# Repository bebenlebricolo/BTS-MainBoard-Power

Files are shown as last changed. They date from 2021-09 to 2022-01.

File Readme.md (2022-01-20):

# BTS-Mainboard-Power's Index

- [BTS-Mainboard-Power's Index](#bts-mainboard-powers-index)
- [Description (Revision 0.2.0)](#description-revision-020)

# Description (Revision 0.2.0)
Beer thermoregulation system mainboard  - power section
This single sided board made a 4 layers PCB stackup carries an H-bridge which drives 8 peltier modules (10x10mm, 12VDC, 6.7A each) in parallel in either direction.

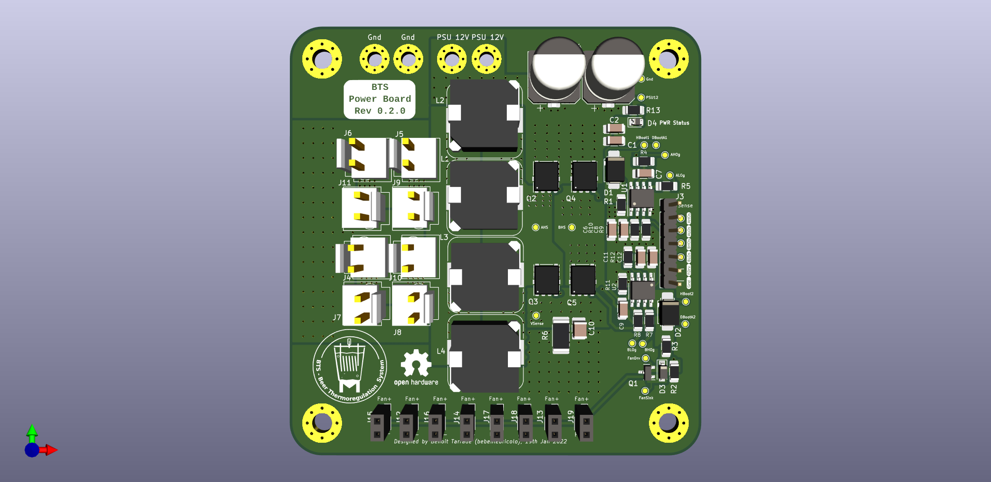
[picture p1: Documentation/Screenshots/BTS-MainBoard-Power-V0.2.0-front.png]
Board screenshot front

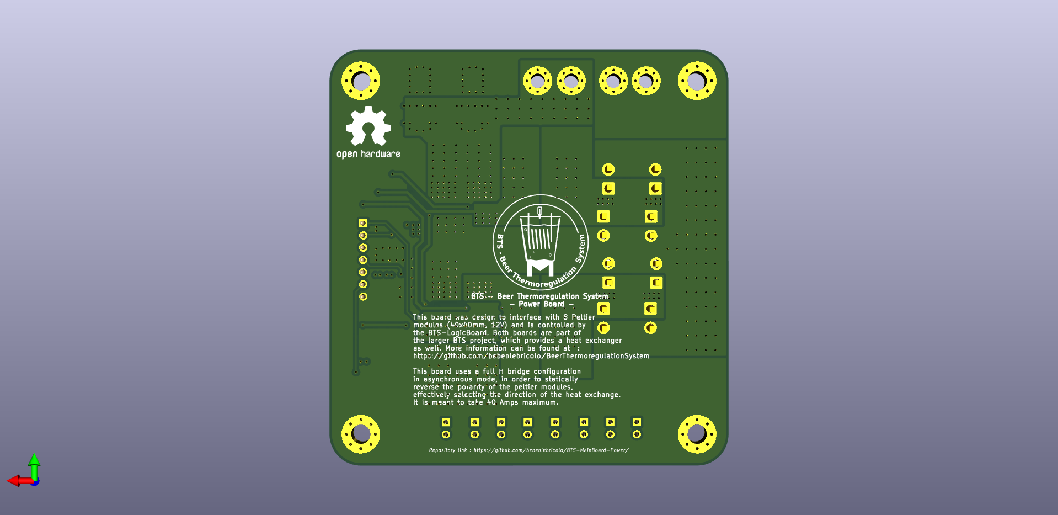
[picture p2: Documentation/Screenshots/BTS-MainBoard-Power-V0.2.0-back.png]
Board screenshot back


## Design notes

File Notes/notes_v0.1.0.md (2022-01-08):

# BTS-Mainboard-Power's Index

- [BTS-Mainboard-Power's Index](#bts-mainboard-powers-index)
- [Description](#description)
- [Modularity](#modularity)
- [Issues and limitations](#issues-and-limitations)

# Description
Beer thermoregulation system mainboard  - power section
This single sided board made with aluminum substrate carries an H-bridge which drives 8 peltier modules (10x10mm, 12VDC, 6.7A each) in parallel in either direction.
It was designed with modularity in mind and good thermal dissipation properties, and this alone drove the design into the aluminum substrate land.

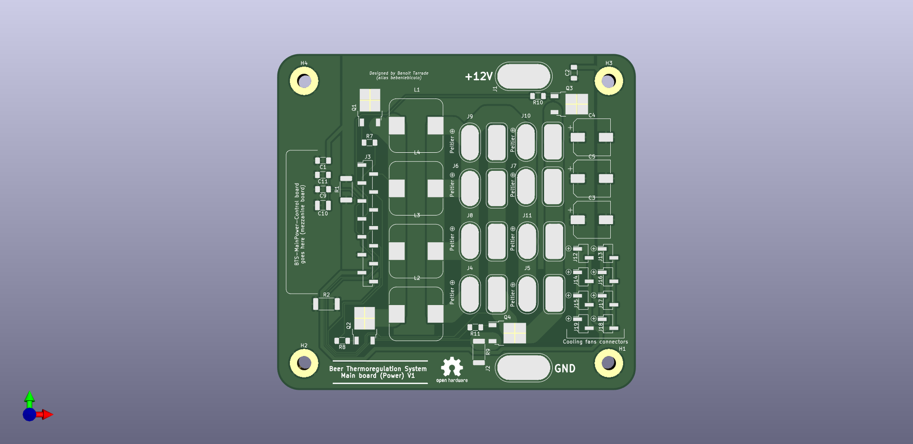
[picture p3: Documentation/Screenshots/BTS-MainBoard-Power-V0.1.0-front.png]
Board screenshot


# Modularity
Modularity is achieved via a standard 2.54 mm pitch header connector which is used to carry the Control board in a mezzanine configuration (boards V0.1.0 and V0.2.0).
It allows to iterate on the control board without having to change anything on the power board itself.

# Issues and limitations
This board has several critical issues that renders it more or less useless.
1. Gate drivers do not implement shoot through protection !
   * As a consequence, I destroyed many mosfets many times because of transient signals being interpreted either as high or low (due to noise on driver's input signal). This resulted in many shoot through occurrences, and if the board effectively spread and dissipated the heat, it was not enough to take the 40A/12V power burst (and potentially even much more).
2. Soldering on this board is a real nightmare
   * I can say the aluminum substrate is very nice when it comes to dissipate heat. So nice that it made the assembly process a real nightmare, without speaking about the single-sidedness of the board which prevents any through-hole component use.
3. The return current track for the ALO mosfet is far to skinny ! It still has the default 0.25 mm width, no doubt as to why it could not handle high powers.
4. Having the mezzanine control board increases chances to pick up EMI and noise, which is not nice.
5. Mosfets are not as "modern" as they could be, I think I can switch to smaller ones that will handle more current just as well
6. Mosfets are spread out on the board the same way they are layed out in schematic : as a consequence they are quite far away from the gate driver, with a ground plane under them still (the aluminum substrate is grounded). Shortening the gate path will help improve their performance and reduce shoot-through potentialities.

All those issues shall be taken care of in the next revision.
Amongts other things, mosfets will be relocated, the board will be switched to a 4 layer configuration and mosfet drivers will finally be carried by this board as well.
I won't use the mezzanine topology anymore, so the whole Beer Thermoregulation System will only need 2 boards instead of 3 (which is more cost effictive).
As we'll be losing the good thermal conductivity of the aluminum substrate, special care shall be taken in order to dissipate the heat properly.
Finally, tracks will also need to be beefed up a little bit, eventually providing a way to add thick copper wire on the surface of the board in order to safely carry the 40A+.

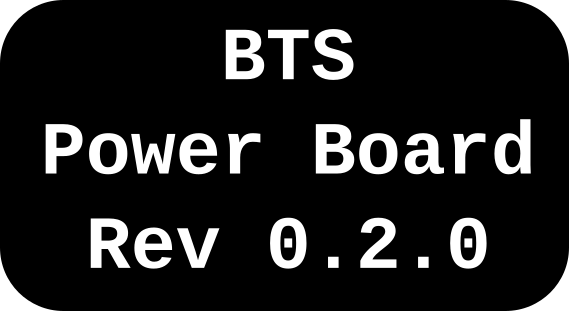
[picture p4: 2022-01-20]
Hardware/Drawings/BoardMainLabel.png

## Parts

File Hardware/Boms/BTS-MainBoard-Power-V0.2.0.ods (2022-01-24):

Reference | Quantity | Value | Footprint | Datasheet
C1 C2 C8 C11 | 4 | 1uF | Capacitor_SMD:C_1206_3216Metric_Pad1.33x1.80mm_HandSolder
C10 | 1 | 22nF | Capacitor_SMD:C_1210_3225Metric_Pad1.33x2.70mm_HandSolder
C3 C4 | 2 | 470uF | Capacitor_SMD:CP_Elec_10x10
C6 C7 C9 C12 | 4 | 100nF | Capacitor_SMD:C_1206_3216Metric_Pad1.33x1.80mm_HandSolder
D1 D2 | 2 | SS56B | BTS-MainBoard-Power:SS56B | https://docs.rs-online.com/99ea/0900766b814bbf94.pdf
D3 | 1 | 1N4148W | Diode_SMD:D_SOD-123 | https://www.vishay.com/docs/85748/1n4148w.pdf
D4 | 1 | LED | Diode_SMD:D_0805_2012Metric
H1 H2 H3 H4 | 4 | MountingHole_Pad | MountingHole:MountingHole_4mm_Pad_Via
H5 H6 H7 H8 | 4 | MountingHole_Pad | MountingHole:MountingHole_3mm_Pad_Via
J12 J13 J14 J15 J16 J17 J18 J19 | 8 | FanConn | Connector_PinSocket_2.54mm:PinSocket_1x02_P2.54mm_Vertical
J3 | 1 | LogicBoardConnector | Connector_PinHeader_2.54mm:PinHeader_1x07_P2.54mm_Vertical
J4 J5 J6 J7 J8 J9 J10 J11 | 8 | PeCon | BTS-MainBoard-Power:TE_1-1123723-2_1x02_P3.96mm_8Amps_Vertical
L1 L2 L3 L4 | 4 | SRP1270-100M | BTS-MainBoard-Power:L_Bourns_SRP1270
Q1 | 1 | DMG3418L | Package_TO_SOT_SMD:SOT-23
Q2 Q3 Q4 Q5 | 4 | NTMFS5H419NL | BTS-MainBoard-Power:NTMFS5G419NL | https://docs.rs-online.com/31fe/0900766b816e75a2.pdf
R1 R3 R4 R5 R7 R8 | 6 | 3.3 | Resistor_SMD:R_1206_3216Metric_Pad1.30x1.75mm_HandSolder
R2 R13 | 2 | 1k | Resistor_SMD:R_1206_3216Metric_Pad1.30x1.75mm_HandSolder
R6 | 1 | 0.01 | Resistor_SMD:R_2512_6332Metric_Pad1.40x3.35mm_HandSolder
R9 R10 R11 R12 | 4 | 220 | Resistor_SMD:R_1206_3216Metric_Pad1.30x1.75mm_HandSolder
TP1 TP2 TP3 TP4 TP5 TP6 TP7 TP8 TP9 TP10 TP11 TP12 TP13 TP14 TP15 TP16 TP17 TP18 TP19 | 19 | TestPoint | TestPoint:TestPoint_Pad_D1.0mm
U1 U2 | 2 | LM5109BMA | Package_SO:SOIC-8_3.9x4.9mm_P1.27mm | http://www.ti.com/lit/ds/symlink/lm5109b.pdf

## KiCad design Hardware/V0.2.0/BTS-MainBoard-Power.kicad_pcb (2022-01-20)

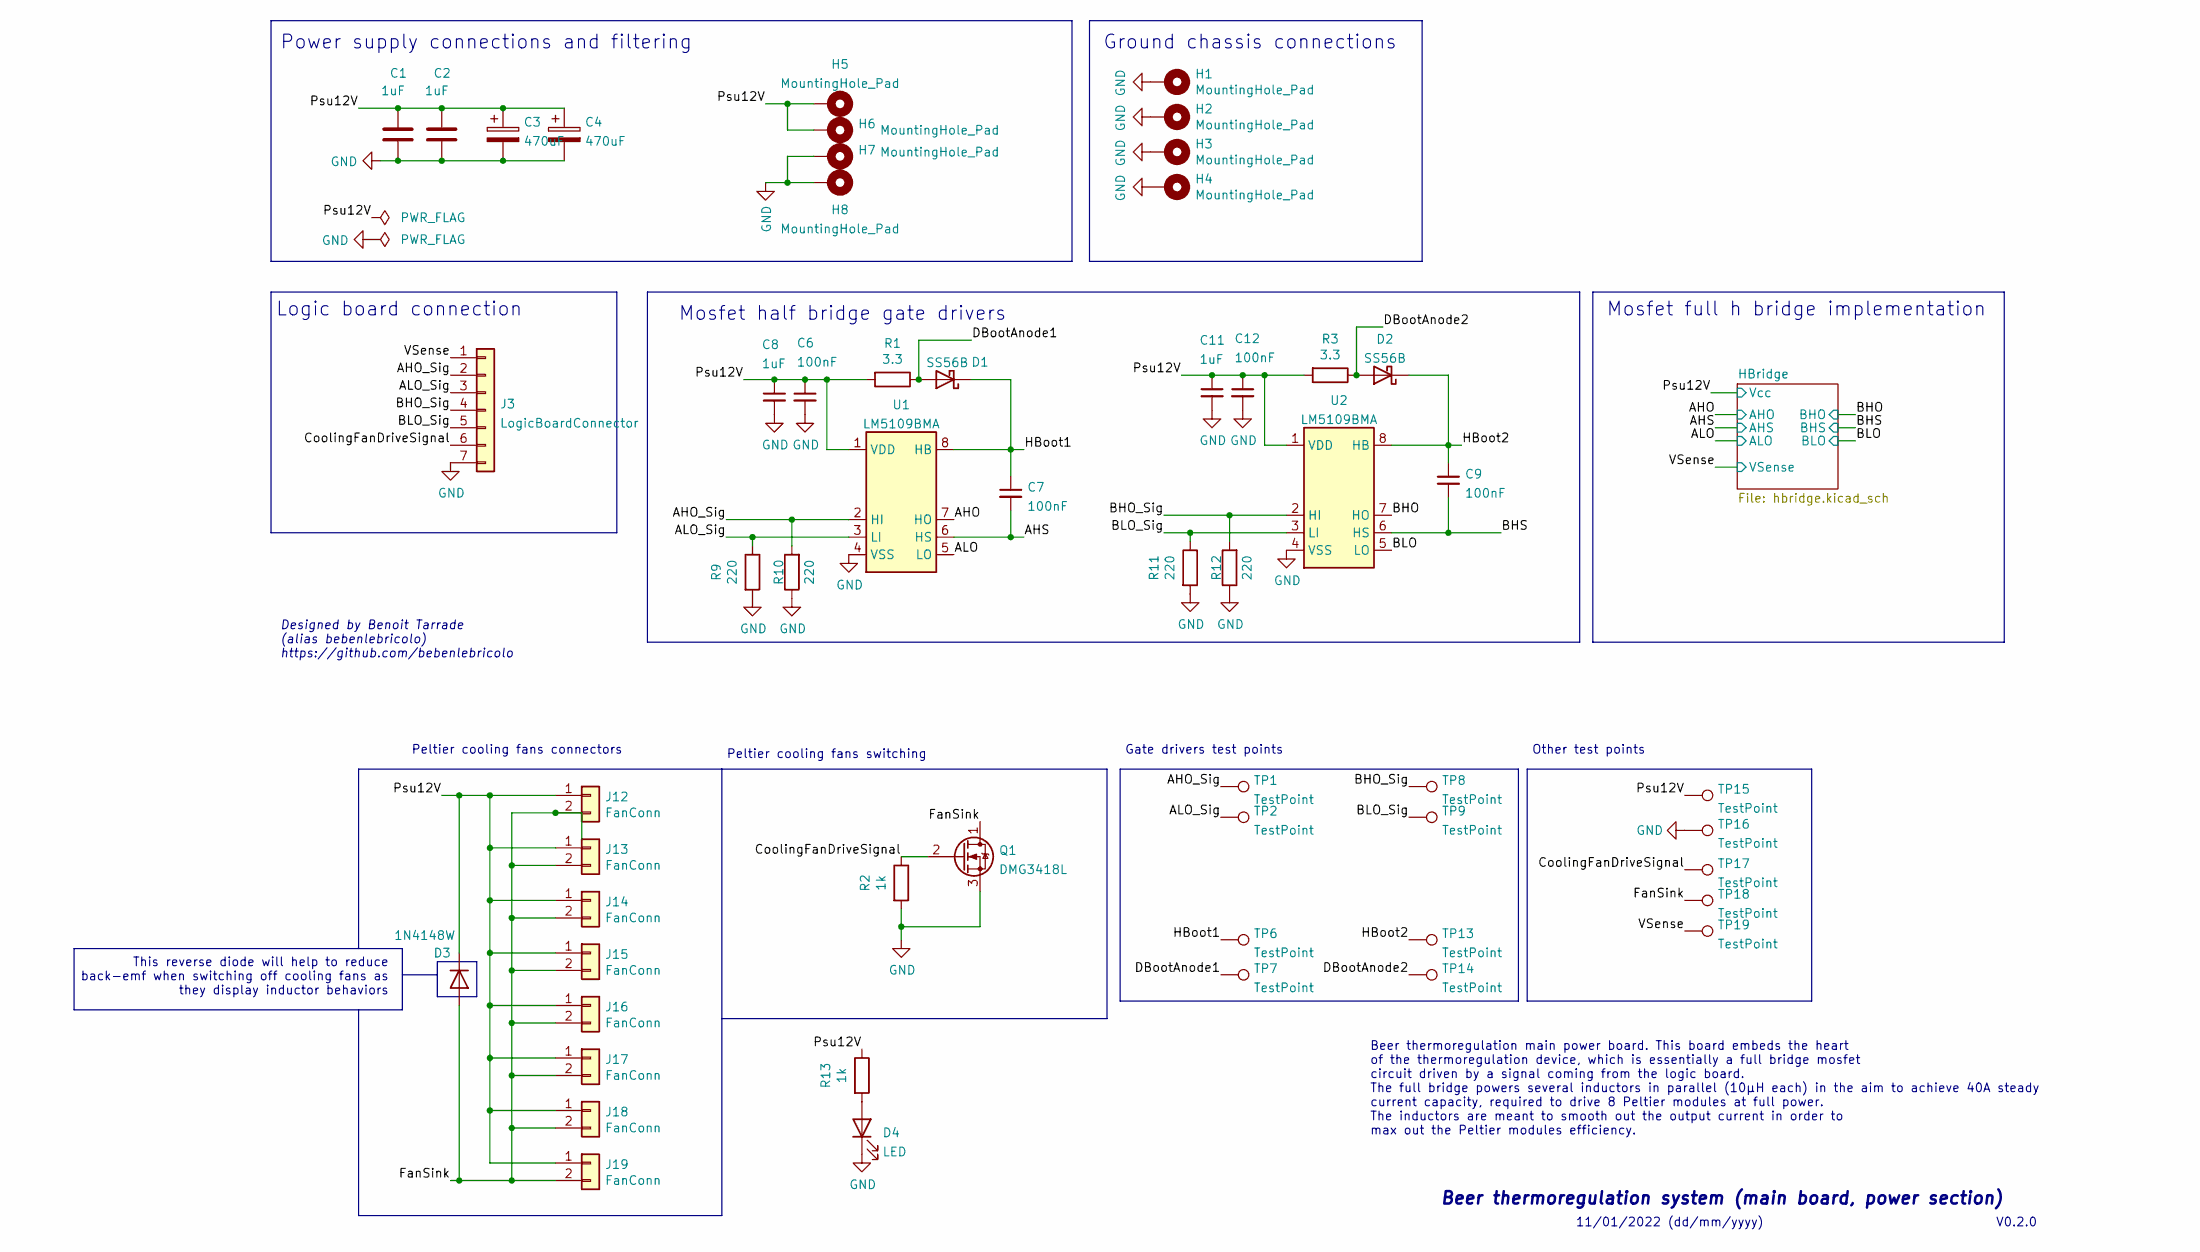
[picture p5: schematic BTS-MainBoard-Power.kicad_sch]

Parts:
C1, C2, C8, C11: 1uF; C_1206_3216Metric_Pad1.33x1.80mm_HandSolder
C3, C4: 470uF; CP_Elec_10x10
C6, C7, C9, C12: 100nF; C_1206_3216Metric_Pad1.33x1.80mm_HandSolder
D1, D2: SS56B
D3: 1N4148W; D_SOD-123
D4: LED; D_0805_2012Metric
H1, H2, H3, H4: MountingHole_Pad; MountingHole_4mm_Pad_Via
H5, H6, H7, H8: MountingHole_Pad; MountingHole_3mm_Pad_Via
J3: LogicBoardConnector; PinHeader_1x07_P2.54mm_Vertical
J12, J13, J14, J15, J16, J17, J18, J19: FanConn; PinSocket_1x02_P2.54mm_Vertical
Q1: DMG3418L; SOT-23
R1, R3: 3.3; R_1206_3216Metric_Pad1.30x1.75mm_HandSolder
R2, R13: 1k; R_1206_3216Metric_Pad1.30x1.75mm_HandSolder
R9, R10, R11, R12: 220; R_1206_3216Metric_Pad1.30x1.75mm_HandSolder
TP1, TP2, TP6, TP7, TP8, TP9, TP13, TP14, TP15, TP16, TP17, TP18, TP19: TestPoint; TestPoint_Pad_D1.0mm
U1, U2: LM5109BMA; SOIC-8_3.9x4.9mm_P1.27mm

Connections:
/AHO: U1.7 (HO); also elsewhere on the board
/AHO_Sig: J3.2, R10.2, TP1.1, U1.2 (HI)
/AHS: C7.2, U1.6 (HS); also elsewhere on the board
/ALO: U1.5 (LO); also elsewhere on the board
/ALO_Sig: J3.3, R9.1, TP2.1, U1.3 (LI)
/BHO: U2.7 (HO); also elsewhere on the board
/BHO_Sig: J3.4, R12.2, TP8.1, U2.2 (HI)
/BHS: C9.2, U2.6 (HS); also elsewhere on the board
/BLO: U2.5 (LO); also elsewhere on the board
/BLO_Sig: J3.5, R11.1, TP9.1, U2.3 (LI)
/CoolingFanDriveSignal: J3.6, Q1.2 (G), R2.1, TP17.1
/DBootAnode1: D1.2 (A), R1.1, TP7.1
/DBootAnode2: D2.2 (A), R3.1, TP14.1
/FanSink: D3.2 (A), J12.2, J13.2, J14.2, J15.2, J16.2, J17.2, J18.2, J19.2, Q1.1 (D), TP18.1
/HBoot1: C7.1, D1.1 (K), TP6.1, U1.8 (HB)
/HBoot2: C9.1, D2.1 (K), TP13.1, U2.8 (HB)
/Psu12V: C1.1, C2.1, C3.1, C4.1, C6.1, C8.1, C11.1, C12.1, D3.1 (K), H5.1, H6.1, J12.1, J13.1, J14.1, J15.1, J16.1, J17.1, J18.1, J19.1, R1.2, R3.2, R13.1, TP15.1, U1.1 (VDD), U2.1 (VDD); also elsewhere on the board
/VSense: J3.1, TP19.1; also elsewhere on the board
GND: C1.2, C2.2, C3.2, C4.2, C6.2, C8.2, C11.2, C12.2, D4.1 (K), H1.1, H2.1, H3.1, H4.1, H7.1, H8.1, J3.7, Q1.3 (S), R2.2, R9.2, R10.1, R11.2, R12.1, TP16.1, U1.4 (VSS), U2.4 (VSS); also elsewhere on the board
unnamed: D4.2 (A), R13.2

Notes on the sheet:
Peltier cooling fans connectors
Gate drivers test points
Logic board connection
Other test points
This reverse diode will help to reduce back-emf when switching off cooling fans as they display inductor behaviors
Mosfet half bridge gate drivers
Designed by Benoit Tarrade (alias bebenlebricolo) https://github.com/bebenlebricolo
11/01/2022 (dd/mm/yyyy)
Ground chassis connections
Peltier cooling fans switching
Mosfet full h bridge implementation
Power supply connections and filtering
V0.2.0
Beer thermoregulation main power board. This board embeds the heart of the thermoregulation device, which is essentially a full bridge mosfet circuit driven by a signal coming from the logic board. The full bridge powers several inductors in parallel (10µH each) in the aim to achieve 40A steady cur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
Beer thermoregulation system (main board, power section)

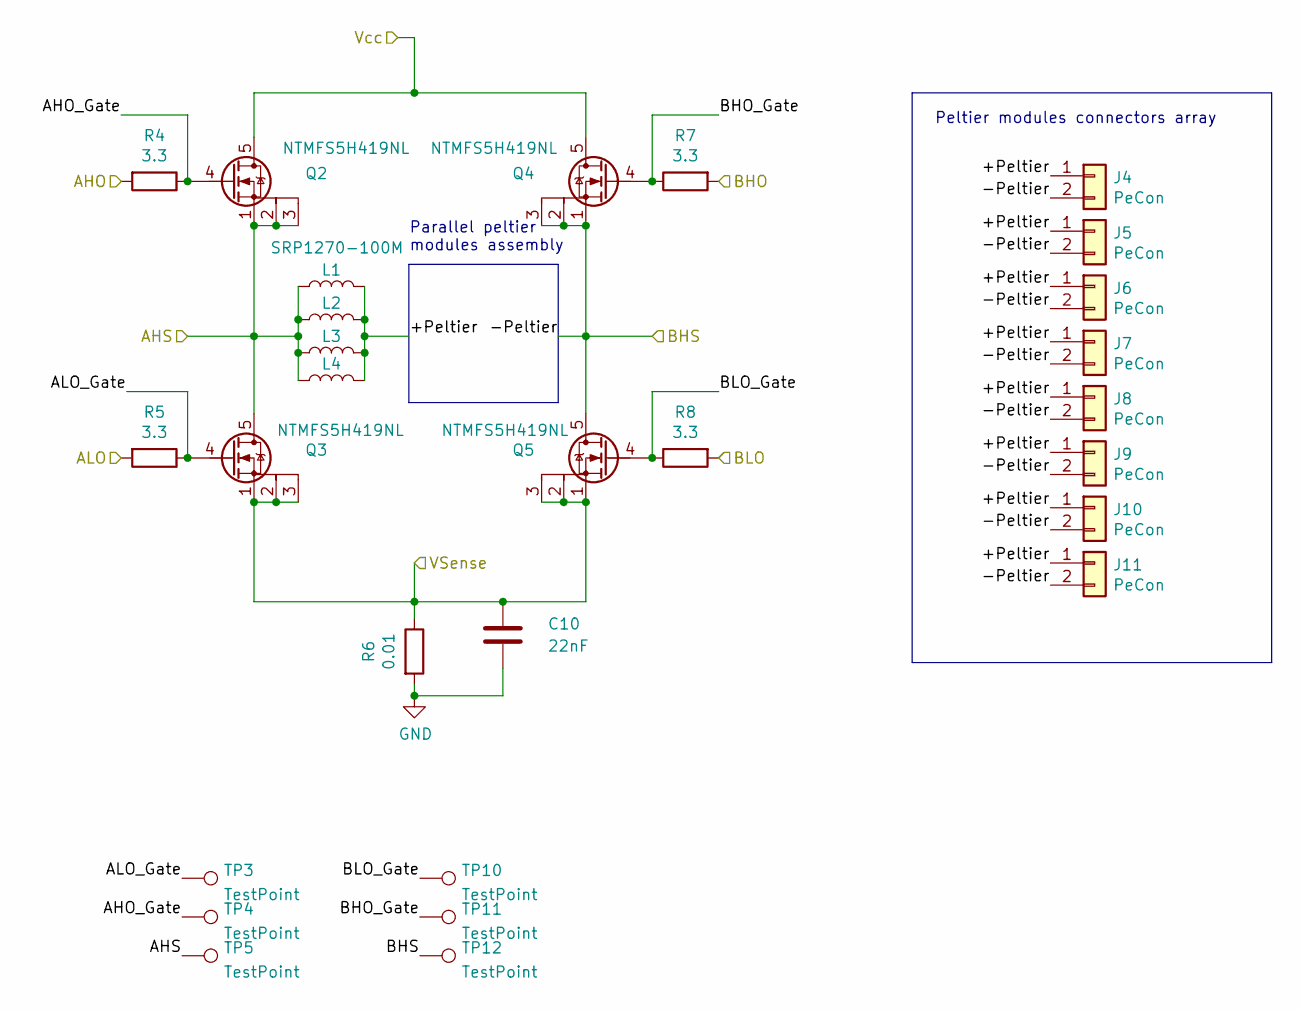
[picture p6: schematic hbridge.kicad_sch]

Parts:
C10: 22nF; C_1210_3225Metric_Pad1.33x2.70mm_HandSolder
J4, J5, J6, J7, J8, J9, J10, J11: PeCon; TE_1-1123723-2_1x02_P3.96mm_8Amps_Vertical
L1, L2, L3, L4: SRP1270-100M; L_Bourns_SRP1270
Q2, Q3, Q4, Q5: NTMFS5H419NL; NTMFS5G419NL
R4, R5, R7, R8: 3.3; R_1206_3216Metric_Pad1.30x1.75mm_HandSolder
R6: 0.01; R_2512_6332Metric_Pad1.40x3.35mm_HandSolder
TP3, TP4, TP5, TP10, TP11, TP12: TestPoint; TestPoint_Pad_D1.0mm

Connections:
/AHO: R4.2; also elsewhere on the board
/AHS: L1.1, L2.1, L3.1, L4.1, Q2.1 (S), Q2.2 (S), Q2.3 (S), Q3.5 (D), TP5.1; also elsewhere on the board
/ALO: R5.2; also elsewhere on the board
/BHO: R7.2; also elsewhere on the board
/BHS: J4.2, J5.2, J6.2, J7.2, J8.2, J9.2, J10.2, J11.2, Q4.1 (S), Q4.2 (S), Q4.3 (S), Q5.5 (D), TP12.1; also elsewhere on the board
/BLO: R8.2; also elsewhere on the board
/HBridge/+Peltier: J4.1, J5.1, J6.1, J7.1, J8.1, J9.1, J10.1, J11.1, L1.2, L2.2, L3.2, L4.2
/HBridge/AHO_Gate: Q2.4 (G), R4.1, TP4.1
/HBridge/ALO_Gate: Q3.4 (G), R5.1, TP3.1
/HBridge/BHO_Gate: Q4.4 (G), R7.1, TP11.1
/HBridge/BLO_Gate: Q5.4 (G), R8.1, TP10.1
/Psu12V: Q2.5 (D), Q4.5 (D); also elsewhere on the board
/VSense: C10.1, Q3.1 (S), Q3.2 (S), Q3.3 (S), Q5.1 (S), Q5.2 (S), Q5.3 (S), R6.1; also elsewhere on the board
GND: C10.2, R6.2; also elsewhere on the board

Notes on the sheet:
Parallel peltier modules assembly
Peltier modules connectors array

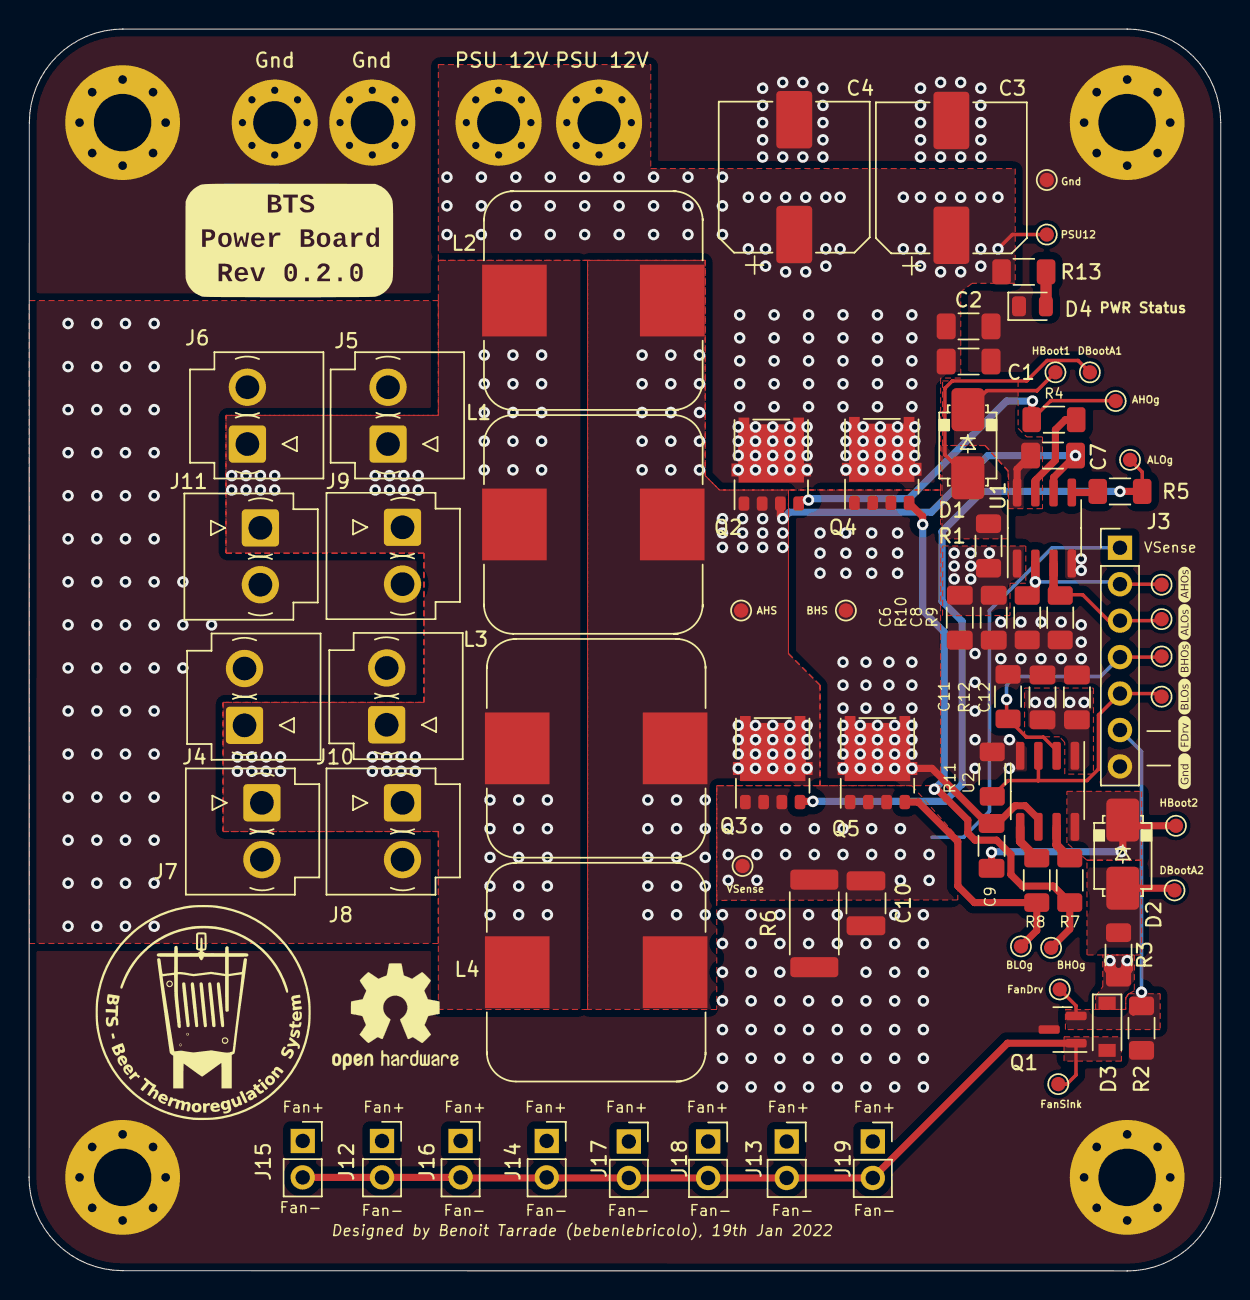
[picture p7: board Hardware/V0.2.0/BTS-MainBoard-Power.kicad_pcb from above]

Board: 4 copper layers, 83.0 x 86.5 mm, 83 parts (0 on the bottom side), 25 nets.

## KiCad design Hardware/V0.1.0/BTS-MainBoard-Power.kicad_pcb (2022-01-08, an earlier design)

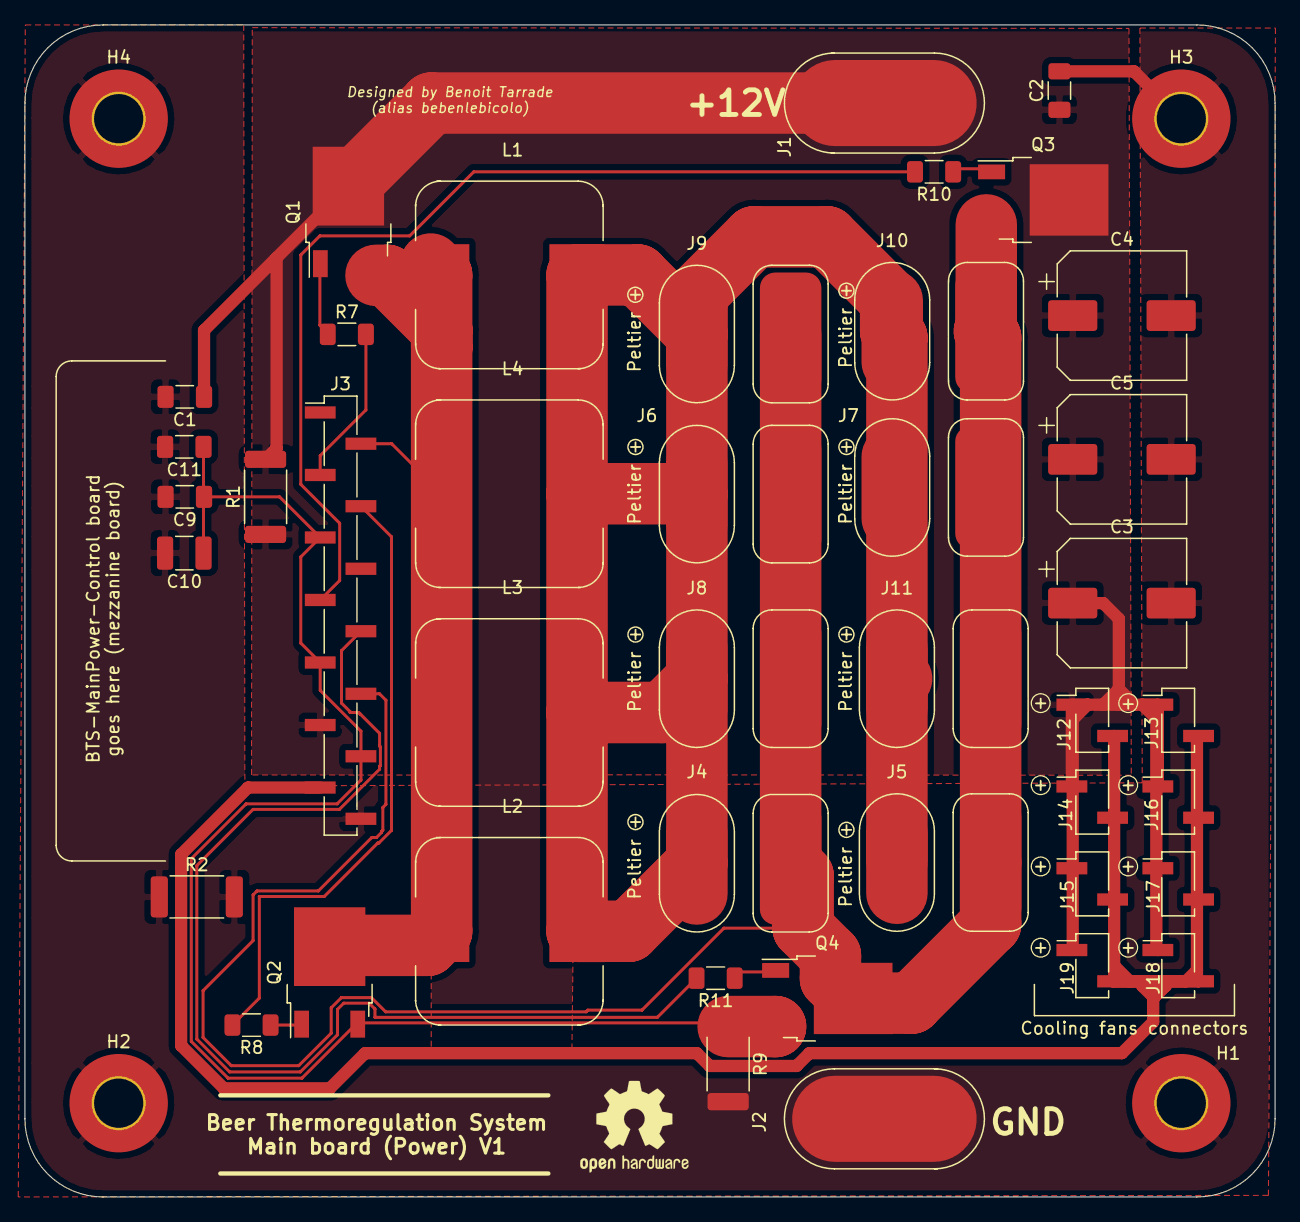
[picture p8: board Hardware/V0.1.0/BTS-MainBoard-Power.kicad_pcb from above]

Board: 2 copper layers, 101.6 x 95.2 mm, 46 parts (0 on the bottom side), 15 nets.

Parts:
C1, C2: 100nF; C_1206_3216Metric_Pad1.33x1.80mm_HandSolder
C3, C4, C5: 470uF; CP_Elec_10x10
C9, C11: 1nF; C_1206_3216Metric_Pad1.33x1.80mm_HandSolder
C10: 22nF; C_1210_3225Metric_Pad1.33x2.70mm_HandSolder
H1, H2, H3, H4: MountingHole_Pad; MountingHole_4mm_Pad_TopOnly
J1: +12VIn; Power_Solder_Pad_7x15mm
J2: GNDIn; Power_Solder_Pad_7x15mm
J3: Conn_01x14; PinHeader_1x14_P2.54mm_Vertical_SMD_Pin1Left
J4, J5, J6, J7, J8, J9, J10, J11: Conn_01x02; Power_Solder_Pad_5x10mm_02
J12, J13, J14, J15, J16, J17, J18, J19: Conn_01x02; PinHeader_1x02_P2.54mm_Vertical_SMD_Pin1Left
L1, L2, L3, L4: SRP1270-100M; L_Bourns_SRP1270
Q1, Q2, Q3, Q4: STD80N6F6; TO-252-2
R1, R2: 0; R_2512_6332Metric_Pad1.40x3.35mm_HandSolder
R7, R8, R10, R11: 3.3; R_1206_3216Metric_Pad1.30x1.75mm_HandSolder
R9: 0.01; R_2512_6332Metric_Pad1.40x3.35mm_HandSolder

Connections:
+12V: C1.1, C2.1, C3.1, C4.1, C5.1, J1.1, J3.11, J12.1, J13.1, J14.1, J15.1, J16.1, J17.1, J18.1, J19.1, Q1.2, Q3.2, R1.1, R1.2
/AHO: J3.3, R7.2
/AHS: J3.2, L1.1, L2.1, L3.1, L4.1, Q1.3, Q2.2
/ALO: J3.4, R8.2
/ALS: C9.1, C10.1, C11.1, J3.5, J3.9, J3.12, Q2.3, Q4.3, R9.1
/BHO: J3.7, R10.2
/BHS: J3.10, J4.2, J5.2, J6.2, J7.2, J8.2, J9.2, J10.2, J11.2, Q3.3, Q4.2
/BLO: J3.8, R11.2
/FanDrive: J3.13, J12.2, J13.2, J14.2, J15.2, J16.2, J17.2, J18.2, J19.2
/PeltierLeft: J4.1, J5.1, J6.1, J7.1, J8.1, J9.1, J10.1, J11.1, L1.2, L2.2, L3.2, L4.2
GND: C1.2, C2.2, C3.2, C4.2, C5.2, C9.2, C10.2, C11.2, H1.1, H2.1, H3.1, H4.1, J2.1, J3.14, R2.1, R2.2, R9.2
unnamed: Q1.1, R7.1
unnamed: Q2.1, R8.1
unnamed: Q3.1, R10.1
unnamed: Q4.1, R11.1

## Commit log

2021-09-10 Initial commit, main board design is pending
    [PeltierSwitchingMainBoard.kicad_pcb, PeltierSwitchingMainBoard.sch, Pseudo BOM.ods]
2021-09-10 Almost finalized designing single board
    [PeltierSwitchingMainBoard.kicad_pcb, PeltierSwitchingMainBoard.sch, Pseudo BOM.ods]
2021-09-10 Added mezzanine footprint
    [PeltierSwitchingMainBoard.sch]
2021-09-10 Modified silkscreen and added cooling fans connectors
    [PeltierSwitchingMainBoard-B_Cu.gbr, PeltierSwitchingMainBoard-B_Mask.gbr, PeltierSwitchingMainBoard-Edge_Cuts.gbr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]
2021-09-10 Updated schematic and silkscreen
    [PeltierSwitchingMainBoard-B_Cu.gbr, PeltierSwitchingMainBoard-B_Mask.gbr, PeltierSwitchingMainBoard-Edge_Cuts.gbr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]
2021-09-10 Moved kicad files into Kicad folder
    [PeltierSwitchingMainBoard.kicad_pcb, PeltierSwitchingMainBoard.sch]
2021-10-05 Renamed Libraries and renamed project files as well
    [BTS-MainBoard-Power.kicad_pcb, BTS-MainBoard-Power.sch]
2021-10-05 Replotted gerber files
    [BTS-MainBoard-Power-B_Cu.gbr, BTS-MainBoard-Power-B_Mask.gbr, BTS-MainBoard-Power-Edge_Cuts.gbr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]
2021-10-05 Updated board with FANDRIVE power signal and silkscreen
    [BTS-MainBoard-Power-B_Cu.gbr, BTS-MainBoard-Power-B_Mask.gbr, BTS-MainBoard-Power-Edge_Cuts.gbr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]
2021-10-05 Created BOM
    [BTS-MainBoard-Power-BOM.ods]
2021-10-05 Updated BOM
    [BTS-MainBoard-Power-BOM.ods]
2021-10-06 Moved BOM out of Kicad folder
    [BTS-MainBoard-Power-BOM.ods]
2022-01-08 Migrated kicad files to version 6
    [BTS-MainBoard-Power.kicad_pcb, BTS-MainBoard-Power.kicad_sch]
2022-01-08 Moved hardware design to its dedicated folder (v0.1.0) and updated notes and readmes
    [BTS-MainBoard-Power-BOM.ods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]
2022-01-11 Started to redesign the schematic
    [BTS-MainBoard-Power.kicad_pcb, BTS-MainBoard-Power.kicad_sch, BTS-MainBoard-Power.sch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]
2022-01-13 Added new footprints and components libraries
2022-01-13 Started first routing steps
    [BTS-MainBoard-Power.kicad_pcb, BTS-MainBoard-Power.kicad_sch, hbridge.kicad_sch]
2022-01-14 Improved zoning thermal layout
    [BTS-MainBoard-Power.kicad_pcb]
2022-01-17 Rewired the whole PCB with much more compact design
    [BTS-MainBoard-Power.kicad_pcb, BTS-MainBoard-Power.kicad_sch, hbridge.kicad_sch]
2022-01-17 Finished routing, now needs improvements
    [BTS-MainBoard-Power.kicad_pcb, BTS-MainBoard-Power.kicad_sch]
2022-01-17 Redid edge cuts
    [BTS-MainBoard-Power.kicad_pcb]
2022-01-17 Improved a bit tracks
    [BTS-MainBoard-Power.kicad_pcb]
2022-01-19 Updated the board with logo and silkscreen improvements
    [BTS-MainBoard-Power.kicad_pcb, BTS-MainBoard-Power.kicad_sch, hbridge.kicad_sch]
2022-01-19 Updated silkscreen and extended BHS zone to the edge of the board
    [BTS-MainBoard-Power.kicad_pcb]
2022-01-20 Reduced vias count, there were too many in there
    [BTS-MainBoard-Power.kicad_pcb]
2022-01-20 Moved Libraries and improved graphics
    [BTS-MainBoard-Power.kicad_pcb]
2022-01-20 Exported BOMS
    [BTS-MainBoard-Power.csv, BTS-MainBoard-Power.kicad_pcb]
2022-01-20 Exported Gerbers and sent board to fab
    [BTS-MainBoard-Power-B_Cu.gbr, BTS-MainBoard-Power-B_Mask.gbr, BTS-MainBoard-Power-Edge_Cuts.gbr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]
